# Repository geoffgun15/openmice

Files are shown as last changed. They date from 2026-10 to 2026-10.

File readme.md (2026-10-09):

# OpenMice

Custom PAW3395 rechargeable mouse, USB wireless receiver, and browser configurator.

Standalone repository: https://github.com/geoffgun15/openmice.
Migrated from the original fork with all eight commits retained and the
confidential PixArt PDF removed from every commit. Historical commit IDs changed.

**A1 is a routed prototype package.** Both boards pass KiCad electrical,
clearance, connectivity and schematic parity checks. Custom runtime and
bootloader builds, factory HEX, runtime UF2 and fabrication exports are included.
**Physical tests are NOT RUN: there is no assembled board.** Review the
[first-article procedure](docs/FIRST_ARTICLE.md) and
[fabrication requirements](docs/FABRICATION.md) before a prototype order.

| Component | Included |
|---|---|
| Mouse | Bare PAW3395, nRF52840 module, 1S LiPo charger/power path, five buttons + scroll |
| Receiver | Custom nRF52840 board, USB-C, BLE-to-USB HID and configuration bridge |
| Firmware | Corrected sensor startup/ID/timing, 16-bit motion, DPI, bindings, persistence |
| Editor | Web Serial, DPI, mouse/keyboard bindings, Apply/Save, import/export and demo |

The radio modules are soldered components on custom PCBs; nice!nano is no longer
used. BLE is the prototype radio; proprietary 1000 Hz wireless is not implemented.

- [Hardware files and validation status](hardware/README.md)
- [Setup, protocol and verification](docs/SETUP.md)
- [Mouse schematic](hardware/mouse/mouse.kicad_sch) / [PCB](hardware/mouse/mouse.kicad_pcb)
- [Receiver schematic](hardware/receiver/receiver.kicad_sch) / [PCB](hardware/receiver/receiver.kicad_pcb)
- [Browser editor](web/index.html)

## Board renders

KiCad assembly renders with all 51 mouse and 18 receiver components fitted.
The sensor, radio module, USB-C, charger and crystal use simplified visual models;
these images do not validate mechanical fit. The battery, main click switches
and scroll encoder connect externally. See [model details](hardware/libraries/3dmodels/README.md).

| Mouse PCB · 64 × 94 mm | Wireless receiver PCB · 28 × 54 mm |
|---|---|
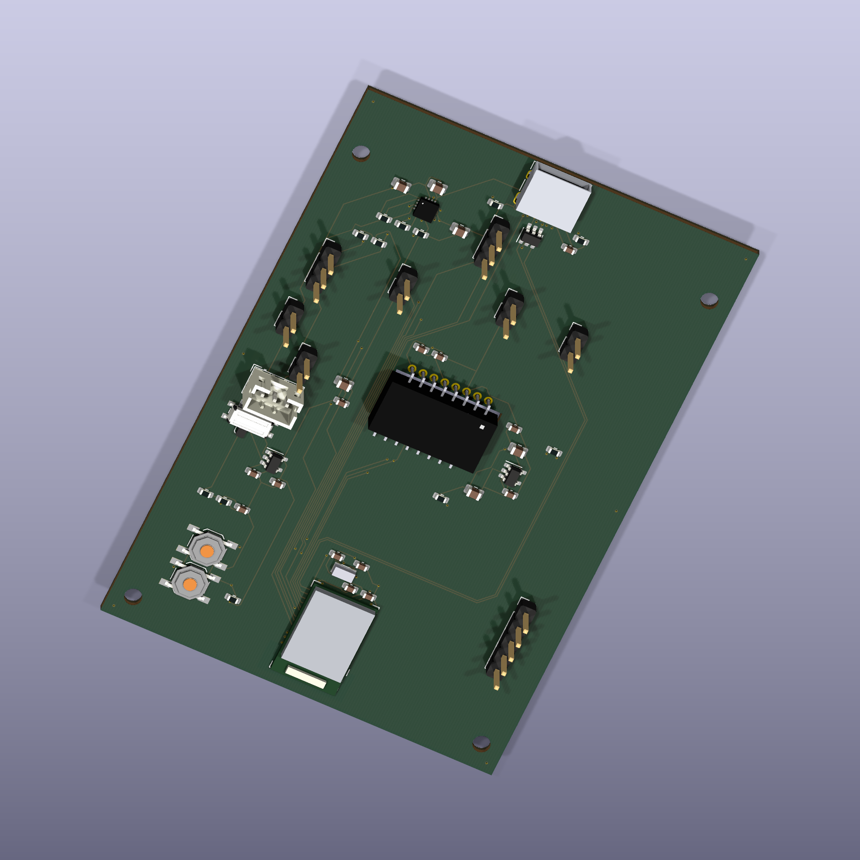
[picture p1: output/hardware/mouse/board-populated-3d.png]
Populated OpenMice mouse PCB with sensor, radio module and connectors
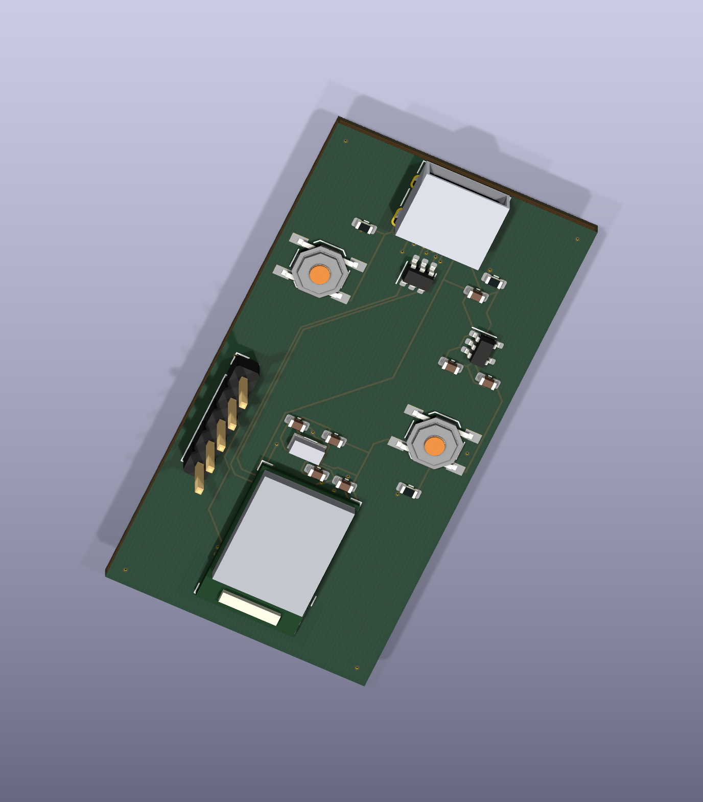
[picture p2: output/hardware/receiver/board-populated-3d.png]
Populated OpenMice wireless receiver PCB with radio module and USB-C
|  |  |

Bare PCB views: [mouse](output/hardware/mouse/board-3d.png) ·
[receiver](output/hardware/receiver/board-3d.png).

## Preview

```sh
python -m http.server 8765 --bind 127.0.0.1 --directory web
```

Open http://127.0.0.1:8765/ in desktop Chrome/Edge. Demo mode works without hardware.
A real connection requires the supplied runtime and mouse/receiver.

Native build details, hashes and CAD export workflow: [BUILD.md](docs/BUILD.md).

## Development

```sh
python -m unittest discover -s tests -v
node --test web/test.mjs
python tools/package_firmware.py
```

`tools/build_hardware.py` regenerates starting placements and overwrites manual edits.
The confidential sensor PDF is excluded from this public repository and its Git history.
Prototype assumptions: LM19-LSI optics,
64 x 94 mm mouse outline, external switch/encoder contacts, and a protected
300 mAh cell with compatible NTC temperature sensing.

Project code: MIT. Vendored KiCad libraries retain their upstream licenses;
see hardware/README.md. Obtain sensor documentation through an authorized source.

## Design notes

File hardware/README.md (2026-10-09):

# Hardware A1: routed prototype candidates

Both custom boards are routed and have zero findings in KiCad 10.0.6 ERC,
DRC, connectivity and schematic parity checks. Manufacturing exports are in
`output/hardware/` and fabrication ZIPs in `output/`. **Physical tests are NOT RUN.**

| Board | Outline | Components | Functional nets |
|---|---|---:|---:|
| Mouse | 64 × 94 mm | 51 | 39 |
| USB-C receiver | 28 × 54 mm | 18 | 13 |

Both boards use soldered Raytac MDBT50Q-1MV2 nRF52840 modules. The mouse has a
bare PAW3395DM-T6QU, 1.9 V sensor/LED rail, 3.0 V MCU/VDDIO rail, external contact
headers for five switches and a scroll encoder, USB-C, SWD and Pair/reset buttons.
The receiver connects by USB-C cable and bridges BLE input/configuration to USB.
Proprietary 1000 Hz wireless is not implemented.

BQ24072 provides charging and system power path for a protected 1S 3.7 V nominal
300 mAh LiPo pack with thermally attached compatible 10k NTC (J3 BAT+, GND, NTC).
USB100 mode caps total input at 100 mA; R_ISET 5.90k programs about 151 mA before
input/system limits, R_ILIM 3.09k is overridden, R_TMR 68k is about 9.1 hours nominal.
The switch is downstream of charging. Firmware battery telemetry is approximate;
pack protection handles over-discharge. USB suspend management is not implemented.

Sensor VDDREG is decoupled only. TLV70019 supplies sensor VDD/LED (5.6 ohm 1%
resistor); TLV70030 supplies VDDIO and MCU VDD/VDDH. DCCH is unconnected. Separate
5.1k CC resistors and USBLC6-2SC6 protect USB; no PD. External 32.768 kHz crystal
loading needs bench verification. The module includes its normal-mode DC/DC parts.

Four layers use outer signal routing and two solid inner GND reference planes,
all-layer antenna keep-outs, routed optical/mounting apertures and charger thermal
vias. USB routing is manually protected. Review the
[fabrication specification](../docs/FABRICATION.md) for stack-up, impedance, filled thermal vias, lens and BOM
requirements before a first-article order. No shell or optical fit validation exists.

Editable native schematics/boards, local libraries, routing DSN/SES, BOM, placement
CSV and CAD-check reports are included. Regeneration overwrites routing; see
[build workflow](../docs/BUILD.md). The unused MouseSwitch_D2F_DRAFT footprint is
not in either BOM and is not validated. Bench bring-up is in
[FIRST_ARTICLE.md](../docs/FIRST_ARTICLE.md).

## References and licenses

- PAW3395DM-T6QU datasheet v1.3 (8 Apr 2024): confidential reference, excluded
  from this public repository; obtain through an authorized source.
- [Raytac module datasheet](https://www.raytac.com/tw/download/index.php?index_id=24).
- [BQ2407x datasheet, including BQ24072](https://www.ti.com/lit/ds/symlink/bq24074.pdf).
- [TLV700 regulators](https://www.ti.com/product/TLV700).
- [KiCad footprints](https://github.com/KiCad/kicad-footprints) and
  [symbols](https://github.com/KiCad/kicad-symbols).

Vendored KiCad data retains upstream CC-BY-SA 4.0 licensing with the KiCad library
exception; see the [library license](https://www.kicad.org/libraries/license/).
Project code uses MIT. The confidential PixArt reference is not distributed.

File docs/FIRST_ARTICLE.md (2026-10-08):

# First article: not yet run

There is no assembled board. Every physical test below is **NOT RUN**. Record
board revision, firmware hashes, equipment, conditions and measured results;
do not infer a pass from the CAD checks or host tests.

1. Inspect solder joints, PAW seating, antenna keep-out and optical alignment.
   Check resistance from USB/battery/system/3.0 V/1.9 V rails to GND before power.
   Leave the battery disconnected initially. Use a current-limited USB supply.
2. Measure MCU/VDDIO at 3.0 V and sensor/LED at 1.9 V under startup and load.
   Check VDDREG against the PAW datasheet. Stop on excess current or heating.
   Confirm USB input stays within the selected 100 mA limit.
3. Connect an SWD probe to SWDIO, SWCLK, GND and target-reference 3.0 V.
   Never drive the target with a 5 V probe supply. Program and verify
   output/native/openmice-factory.hex, including UICR and bootloader settings.
   Confirm normal startup, Pair held during reset enters UF2, and SWD recovery.
4. Copy the mouse/receiver application payload to the corresponding CIRCUITPY
   drive and power-cycle. Confirm USB HID mouse, keyboard and configuration
   CDC enumerate; recovery storage remains accessible. Test runtime UF2 update.
5. Capture SPI with a logic analyser: mode 3, <=4 MHz, reset and startup waits,
   1 ms ±1% ready polling cadence, burst address delay, and CS timing. Confirm
   product ID 0x51/inverse 0xAE. Exercise unsuccessful initialization recovery.
   The compiled DWT polling helper fails explicitly on missed cadence, but this
   does not replace a waveform measurement.
6. Run `python tools/bench_config.py --port COMx --report results/wired.json`
   after installing pyserial. It tests hello/get, an invalid DPI rejection and
   live set/readback, then restores the original live configuration. It does
   not save or move the pointer. Repeat through the paired receiver.
7. Exercise DPI 50, 800, 1600, 9000 and 26000. Measure counts over a calibrated
   travel distance in both axes, jitter and lift-off on several surfaces.
   Test all five contacts, wheel direction, debounce and every binding class,
   including overlapping keyboard chords and release after disconnect.
8. Apply and Save a distinct configuration in the browser. Power-cycle and Read
   device. Cut power during repeated saves; recover the old or completed new
   profile, never corrupted data. Recheck receiver pairing after configuration
   saves and across power cycles (separate NVM erase pages).
9. Pair both devices after startup. Test automatic reconnect, receiver offline
   errors, fragmented traffic, interference/range and stale-input release within
   the 500 ms watchdog allowance. Record motion/input latency, packet loss and
   current; no wireless polling-rate or battery-life claim exists yet.
10. Connect the specified protected battery with NTC after polarity/ratings
    checks. Measure USB100 charging, charge termination, system power-path
    transitions, NTC hot/cold inhibition and case/charger temperature. Test with
    the battery supplier's limits. Measure active, idle and switched-off current
    and run battery endurance. MCU deep sleep/firmware cutoff are not implemented.

Acceptance: all physical measurements meet the applicable component datasheets
and chosen pack specifications; USB, input and persistence behave as above.
Document failures and revise the board/firmware before another article or larger
order. EMC/ESD and regulatory tests are separate from this prototype bring-up.

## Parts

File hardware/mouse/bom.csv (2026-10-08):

Reference | Value / part | Footprint | X mm | Y mm | Block
U1 | MDBT50Q-1MV2 | Raytac_MDBT50Q | 32 | 84 | controller
J1 | USB-C HRO TYPE-C-31-M-12 | USB_C | 32 | 3.6 | USB
U2 | USBLC6-2SC6 | SOT-23-6 | 38 | 7.6 | USB
R1 | 5.1k 1% | R_0603_1608Metric | 26 | 7.6 | USB
R2 | 5.1k 1% | R_0603_1608Metric | 29 | 7.6 | USB
U3 | TLV70030DDCR | SOT-23-5 | 13 | 61 | power
C1 | 1uF 10V X7R | C_0603_1608Metric | 11 | 64 | power
C2 | 4.7uF 6.3V X5R | C_0603_1608Metric | 15 | 64 | power
C3 | 100nF 10V X7R | C_0603_1608Metric | 32 | 75 | controller
C4 | 100nF 10V X7R | C_0603_1608Metric | 35 | 75 | controller
C5 | 1uF 10V X7R | C_0603_1608Metric | 35 | 10.6 | USB
Y1 | 32.768kHz 12.5pF ABS07 | Crystal_SMD_3215-2Pin_3.2x1.5mm | 30 | 73 | controller
C6 | 18pF C0G (tune) | C_0603_1608Metric | 28 | 71 | controller
C7 | 18pF C0G (tune) | C_0603_1608Metric | 32 | 71 | controller
J2 | SWD: VDD / SWDIO / SWDCLK / GND / RESET | PinHeader_1x05_P2.54mm_Vertical | 57 | 67 | debug
SW1 | PAIR TL3342 | SW_SPST_TL3342 | 10 | 78 | controls
SW2 | RESET TL3342 | SW_SPST_TL3342 | 10 | 84 | controls
R3 | 10k | R_0603_1608Metric | 14 | 84 | controller
U4 | PAW3395DM-T6QU | PAW3395DM_T6QU | 32 | 44 | sensor
U5 | TLV70019DDCR | SOT-23-5 | 46 | 48 | sensor
C8 | 1uF 10V X7R | C_0603_1608Metric | 47 | 51 | sensor
C9 | 10uF 6.3V X5R | C_0805_2012Metric | 45 | 44 | sensor
C10 | 100nF X7R | C_0603_1608Metric | 43 | 41 | sensor
C11 | 4.7uF X5R | C_0603_1608Metric | 25 | 35 | sensor
C12 | 100nF X7R | C_0603_1608Metric | 28 | 35 | sensor
C13 | 10uF X5R | C_0805_2012Metric | 17 | 45 | sensor
C14 | 100nF X7R | C_0603_1608Metric | 18 | 48 | sensor
C15 | 33uF 6.3V X5R | C_0805_2012Metric | 42 | 53 | sensor
R4 | 5.6R 1% | R_0603_1608Metric | 40 | 52 | sensor
R5 | 10k | R_0603_1608Metric | 50 | 42 | sensor
U6 | BQ24072RGTR | VQFN-16-1EP_3x3mm_P0.5mm_EP1.45x1.45mm | 16 | 14 | battery
J3 | Protected 1S 300mAh + 10k NTC (BAT/GND/NTC) | JST_PH_B3B-PH-K_1x03_P2.00mm_Vertical | 6 | 53 | battery
R6 | 5.90k 1% | R_0603_1608Metric | 11 | 18 | battery
R7 | 3.09k 1% | R_0603_1608Metric | 14 | 18 | battery
R8 | 68k 1% | R_0603_1608Metric | 17 | 18 | battery
C16 | 1uF 10V X7R | C_0805_2012Metric | 16 | 10 | battery
C17 | 10uF 6.3V X5R | C_0805_2012Metric | 20 | 17 | battery
C18 | 10uF 6.3V X5R | C_0805_2012Metric | 11 | 12 | battery
SW3 | Power PCM12 | SW_SPDT_PCM12 | 7 | 63 | battery
R9 | 100k 1% | R_0603_1608Metric | 6 | 70 | battery
R10 | 100k 1% | R_0603_1608Metric | 9 | 70 | battery
C19 | 100nF X7R | C_0603_1608Metric | 12 | 70 | battery
R11 | 100k | R_0603_1608Metric | 9 | 22 | battery
R12 | 100k | R_0603_1608Metric | 12 | 22 | battery
J4 | Charger status: GND / PGOOD / CHG | PinHeader_1x03_P2.54mm_Vertical | 6 | 26 | battery
J5 | BUTTON_LEFT contact | PinHeader_1x02_P2.54mm_Vertical | 18 | 25 | controls
J6 | BUTTON_RIGHT contact | PinHeader_1x02_P2.54mm_Vertical | 44 | 25 | controls
J7 | BUTTON_MIDDLE contact | PinHeader_1x02_P2.54mm_Vertical | 30 | 20 | controls
J8 | BUTTON_BACK contact | PinHeader_1x02_P2.54mm_Vertical | 5 | 39 | controls
J9 | BUTTON_FORWARD contact | PinHeader_1x02_P2.54mm_Vertical | 5 | 44 | controls
J10 | Encoder: A / GND / B | PinHeader_1x03_P2.54mm_Vertical | 27 | 12 | controls

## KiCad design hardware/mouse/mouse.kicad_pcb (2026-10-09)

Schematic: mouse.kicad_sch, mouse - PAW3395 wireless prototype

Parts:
C1, C5, C8: 1uF 10V X7R; C_0603_1608Metric
C2: 4.7uF 6.3V X5R; C_0603_1608Metric
C3, C4: 100nF 10V X7R; C_0603_1608Metric
C6, C7: 18pF C0G (tune); C_0603_1608Metric
C9, C17, C18: 10uF 6.3V X5R; C_0805_2012Metric
C10, C12, C14, C19: 100nF X7R; C_0603_1608Metric
C11: 4.7uF X5R; C_0603_1608Metric
C13: 10uF X5R; C_0805_2012Metric
C15: 33uF 6.3V X5R; C_0805_2012Metric
C16: 1uF 10V X7R; C_0805_2012Metric
J1: USB-C HRO TYPE-C-31-M-12; USB_C
J2: SWD: VDD / SWDIO / SWDCLK / GND / RESET; PinHeader_1x05_P2.54mm_Vertical
J3: Protected 1S 300mAh + 10k NTC (BAT/GND/NTC); JST_PH_B3B-PH-K_1x03_P2.00mm_Vertical
J4: Charger status: GND / PGOOD / CHG; PinHeader_1x03_P2.54mm_Vertical
J5: BUTTON_LEFT contact; PinHeader_1x02_P2.54mm_Vertical
J6: BUTTON_RIGHT contact; PinHeader_1x02_P2.54mm_Vertical
J7: BUTTON_MIDDLE contact; PinHeader_1x02_P2.54mm_Vertical
J8: BUTTON_BACK contact; PinHeader_1x02_P2.54mm_Vertical
J9: BUTTON_FORWARD contact; PinHeader_1x02_P2.54mm_Vertical
J10: Encoder: A / GND / B; PinHeader_1x03_P2.54mm_Vertical
R1, R2: 5.1k 1%; R_0603_1608Metric
R3, R5: 10k; R_0603_1608Metric
R4: 5.6R 1%; R_0603_1608Metric
R6: 5.90k 1%; R_0603_1608Metric
R7: 3.09k 1%; R_0603_1608Metric
R8: 68k 1%; R_0603_1608Metric
R9, R10: 100k 1%; R_0603_1608Metric
R11, R12: 100k; R_0603_1608Metric
SW1: PAIR TL3342; SW_SPST_TL3342
SW2: RESET TL3342; SW_SPST_TL3342
SW3: Power PCM12; SW_SPDT_PCM12
U1: MDBT50Q-1MV2; Raytac_MDBT50Q
U2: USBLC6-2SC6; SOT-23-6
U3: TLV70030DDCR; SOT-23-5
U4: PAW3395DM-T6QU; PAW3395DM_T6QU
U5: TLV70019DDCR; SOT-23-5
U6: BQ24072RGTR; BQ24072_RGT0016C
Y1: 32.768kHz 12.5pF ABS07; Crystal_SMD_3215-2Pin_3.2x1.5mm

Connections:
/BATTERY: C18.1, J3.1, R9.1, U6.2 (BAT), U6.3 (BAT)
/BATTERY_ADC: C19.1, R9.2, R10.1, U1.20 (P0.04/AIN2)
/BATTERY_NTC: J3.3, U6.1 (TS)
/BUTTON_BACK: J8.1, U1.46 (P0.22)
/BUTTON_FORWARD: J9.1, U1.48 (P0.24)
/BUTTON_LEFT: J5.1, U1.44 (P0.20)
/BUTTON_MIDDLE: J7.1, U1.45 (P0.23)
/BUTTON_RIGHT: J6.1, U1.43 (P0.21)
/CC1: J1.A5, R1.1
/CC2: J1.B5, R2.1
/CHARGER_ILIM: R7.1, U6.12 (ILIM)
/CHARGER_ISET: R6.1, U6.16 (ISET)
/CHARGER_TMR: R8.1, U6.14 (TMR)
/CHARGING: J4.3, R12.2, U6.9 (CHG)
/ENCODER_A: J10.1, U1.49 (P0.25)
/ENCODER_B: J10.3, U1.19 (P0.26)
/GND: C1.2, C2.2, C3.2, C4.2, C5.2, C6.2, C7.2, C8.2, C9.2, C10.2, C11.2, C12.2, C13.2, C14.2, C15.2, C16.2, C17.2, C18.2, C19.2, J1.A1, J1.A12, J1.B1, J1.B12, J1.S1, J2.4, J3.2, J4.1, J5.2, J6.2, J7.2, J8.2, J9.2, J10.2, R1.2, R2.2, R6.2, R7.2, R8.2, R10.2, SW1.2, SW2.2, U1.1 (GND), U1.2 (GND), U1.15 (GND), U1.33 (GND), U1.55 (GND), U2.2, U3.2, U4.3 (GND), U4.8 (GNDIO), U5.2, U6.4 (CE), U6.5 (EN2), U6.6 (EN1), U6.8 (VSS), U6.15 (TD), U6.17 (EP)
/LF_XL1: C6.1, U1.17 (XL1/P0.00), Y1.1
/LF_XL2: C7.1, U1.18 (XL2/P0.01), Y1.2
/MCU_RESET: J2.5, R3.2, SW2.1, U1.40 (~RESET~/P0.18)
/PAIR: SW1.1, U1.16 (P0.27)
/POWER_GOOD: J4.2, R11.2, U6.7 (PGOOD)
/SENSOR_IRQ: U1.27 (TRACEDATA2/P0.11), U4.9 (MOTION)
/SENSOR_LED_P: R4.2, U4.15 (LED_P)
/SENSOR_NCS: U1.38 (P0.16), U4.13 (NCS)
/SENSOR_RESET: U1.41 (P0.17), U4.14 (NRESET)
/SENSOR_VDDREG: C11.1, C12.1, U4.5 (VDDREG)
/SPI_MISO: R5.2, U1.39 (P0.15), U4.12 (MISO)
/SPI_MOSI: U1.37 (P0.13), U4.11 (MOSI)
/SPI_SCLK: U1.36 (P0.14), U4.10 (SCLK)
/SWDCLK: J2.3, U1.53 (SWDCLK)
/SWDIO: J2.2, U1.51 (SWDIO)
/SYSTEM: C17.1, SW3.1, U6.10 (OUT), U6.11 (OUT)
/SYSTEM_ON: C1.1, SW3.2, U3.1, U3.3
/USB_DM: J1.A7, J1.B7, U1.34 (D-), U2.3, U2.4
/USB_DP: J1.A6, J1.B6, U1.35 (D+), U2.1, U2.6
/USB_VBUS: C5.1, C16.1, J1.A4, J1.A9, J1.B4, J1.B9, U1.32 (VBUS), U2.5, U6.13 (IN)
/VDD_1V9: C9.1, C10.1, C15.1, R4.1, U4.4 (VDD), U5.5
/VDD_3V0: C2.1, C3.1, C4.1, C8.1, C13.1, C14.1, J2.1, R3.1, R5.1, R11.1, R12.1, U1.28 (VDD), U1.30 (VDDH), U3.5, U4.7 (VDDIO), U5.1, U5.3

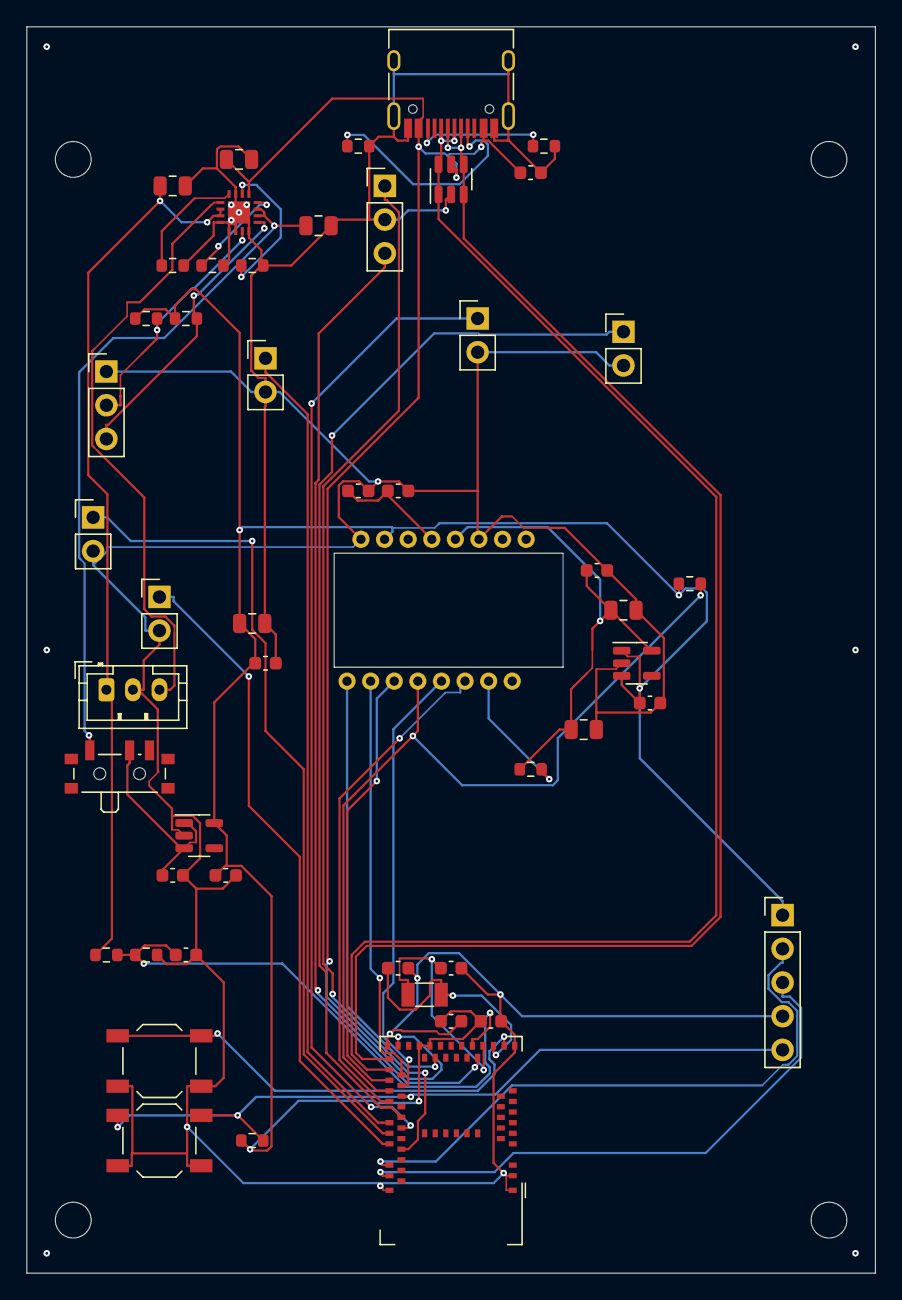
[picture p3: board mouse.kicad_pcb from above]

Board: 4 copper layers, 64.0 x 94.0 mm, 51 parts (0 on the bottom side), 39 nets.

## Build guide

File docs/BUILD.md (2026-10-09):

# Rebuild and verification

The supplied native files were compiled with ARM GNU 13.2.Rel1 on Windows using
MSYS2 make 4.4.1, Python 3.12, GCC 15.3 for mpy-cross, and the source commits in
output/native/manifest.json. Flash use is recorded in runtime-size.json. Both
devices share the runtime/bootloader; their code.py payloads differ.

CircuitPython 9.2.8 commit 361dbc02066f8d2b83c3a7f1f4993a9a590d1239 and Adafruit
nRF52 Bootloader 0.11.0 commit c67f0bcf0fa8e841426335b1bbde91cda6ca1f50 are used.
S140 **6.1.1 must match in both**. The board enables internal storage, a 12 KiB
NVM allocation, the external 32.768 kHz crystal, and no LED. BLE/Register/BusDevice
libraries are frozen from CircuitPython's pinned submodule commits.

Prerequisites: git, GNU make, native GCC, Python, ARM GNU 13.2.Rel1 on PATH;
CircuitPython's requirements-dev.txt Python build dependencies, intelhex and
adafruit-nrfutil 0.5.3.post16. Pin setuptools below 81 for that older DFU utility
(the supplied build used 80.9.0). MSYS2 also needs diffutils and unzip. On MSYS2,
clear the Windows `OS` environment variable before make and use POSIX paths.

Run `bash tools/build_native.sh /absolute/path/to/new-build-directory` from a
configured shell. This creates fresh checkouts; it does not erase existing ones.
Full recursive submodules can be large. The script reflects the successful build
steps; the supplied binaries were built incrementally, not in a second clean-room
run. Exact source/submodule provenance and output SHA-256 hashes are included.

The narrowly scoped PacketBuffer header patch exposes an internal declaration
needed by _bleio when optional BLE serial/file workflows are disabled. The native
openmice_native.poll_ready helper uses the Cortex-M4 cycle counter for the PAW
startup polling cadence and detects missed deadlines; radio interrupts remain
enabled. Other sensor transactions remain Python driver code. Physical SPI
waveforms and USB enumeration must still be measured.

Host checks: `python -m unittest discover -s tests -v` and
`node --test web/test.mjs`. Regenerate the application ZIPs with
`python tools/package_firmware.py`.

CAD tooling: KiCad 10.0.6, Freerouting 2.5.0, Java 25.0.4.1.
The generator overwrites the native designs with unrouted starting placements:

1. Run tools/build_hardware.py with Python.
2. Run tools/prepare_routing.py using KiCad's Python/pcbnew.
3. Export native schematic netlists with `kicad-cli sch export netlist` into each
   board's .net file. Hand USB routes are locked and included in the DSN.
4. Run Freerouting headless with the board's routing/*.dsn to produce *.ses, or
   reuse the checked-in session if geometry and electrical model are unchanged.
   Route only outer layers; use 0.17 mm defaults with 0.125 mm minimum neckdowns.
5. Run tools/finalize_board.py using KiCad Python: import sessions, clean redundant
   vias, complete receiver power/ground, add charger thermal vias, two GND planes,
   perimeter ties, all-layer RF keep-out, and schematic NC-net assignments.
6. Using KiCad's Python/pcbnew, run
   `python tools/export_hardware.py --kicad-cli /path/to/kicad-cli`.
   It refuses fabrication exports if ERC, DRC, connectivity or parity fails.

Run `python tools/verify_release.py` to verify native image records/checksums,
UF2 family/content, nonoverlapping factory regions, native manifest, CAD results
and matching application/fabrication archives. It refreshes hardware output hashes
after optional PNG previews are rendered.

Final native reports have zero findings on both boards. Configured rule checks
are CAD checks; stack-up impedance, mechanical fit and bench operation are not
proved by these reports. Check manufacturing assumptions in FABRICATION.md.

Project code is MIT. Native bundles include CircuitPython, Adafruit bootloader,
Nordic SoftDevice and frozen-library license files. Vendored KiCad footprints
retain their upstream licensing. The confidential PixArt PDF is excluded
from this public repository and its complete Git history.

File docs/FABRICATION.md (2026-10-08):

# A1 prototype fabrication specification

The supplied files are routed prototype candidates. Physical validation is NOT
RUN. Before ordering a first article, confirm the stack-up, lens fit and assembly
process below with the fabricator. This package is not a production release.

| Item | Specification |
|---|---|
| Mouse outline | 64 × 94 mm, four 2.7 mm routed mounting apertures |
| Receiver outline | 28 × 54 mm, USB-C cable connection |
| Layers | F.Cu signals / In1.Cu GND / In2.Cu GND / B.Cu signals |
| Finished thickness | Nominal 1.6 mm, confirm optics before manufacture |
| Outer copper | 35 µm nominal |
| Outer dielectric | Nominal 0.10 mm, FR4 Er approximately 4.2 |
| Inner core | Approximately 1.26 mm; vendor completes stack-up |
| USB impedance | Target 90 Ω differential; vendor must solve stack-up |
| USB geometry | 0.17 mm width / 0.15 mm gap; impedance not measured |
| Minimum track/clearance | 0.125 / 0.125 mm |
| Through vias | 0.50 mm copper / 0.20 mm finished drill |
| Copper to cut edge | 0.25 mm minimum |
| Finish | ENIG recommended for prototype assembly |

Gerbers include four copper layers, masks, silk, paste and Edge.Cuts. Excellon
files separate plated and nonplated holes. Edge.Cuts contains mouse optical and
mounting apertures: route these, do not treat them as artwork. No blind vias.
Review the exported drill-map SVG and copper layers against the native board.

The BQ24072 exposed pad is 1.68 mm square, with a 1.55 mm paste aperture
(approximately 85% coverage) and four 0.20 mm thermal vias. **Fill/plug and cap
these vias before assembly** to prevent solder loss. One corner via is replaced
by a central via to avoid the rear configuration trace. All other vias are
tented. Confirm paste thickness and reflow profile with the assembler.

The PAW3395 is through-hole and needs its matching optical assembly. The
17.26 × 8.60 mm aperture is based on the supplied sensor drawing. LM19-LSI lens,
1.6 mm board fit, sensor seating height and lens-to-surface distance require an
actual mechanical fit check. No shell is supplied. Switches and encoder attach
to headers; the bare board is not a complete enclosed mouse.

Keep copper/components/cables/metal away from the radio antenna areas on all
layers. Housing and battery placement can change antenna performance. Raytac
module approval does not establish approval of this complete product.

BOM values and placement CSV are engineering inputs, not a turnkey assembly
order. Confirm supplier part numbers/package variants, regulator pinouts, USB-C
connector HRO TYPE-C-31-M-12, PAW3395DM-T6QU and Raytac MDBT50Q-1MV2. Use 1%
charger/LED/divider resistors, X5R/X7R capacitors with voltage and DC-bias margin,
USB capacitors rated at least 10 V, and battery/system capacitors at least 6.3 V.
Do not silently substitute charger, optics or antenna modules.

Use a protected single-cell 3.7 V LiPo pack, nominal 300 mAh, with compatible
thermally attached 10 kΩ NTC. J3 is BAT+, GND, NTC. Confirm polarity before
connection. Charger USB100 selection caps total input at 100 mA; actual charge
current is lower while the system runs. See FIRST_ARTICLE.md for bring-up.

Checks: KiCad 10.0.6 ERC, DRC and schematic parity are stored under
output/hardware/{mouse,receiver}. Zero findings establish CAD consistency under
the configured rules, not optical, RF, thermal, EMC or physical functionality.

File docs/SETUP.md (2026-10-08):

# Setup, protocol and verification

**A1 status:** routed boards pass KiCad ERC/DRC and schematic parity. Native
runtime and bootloader are compiled and packaged. Physical tests are NOT RUN.
Read [first-article procedure](FIRST_ARTICLE.md) before powering an assembled board.

## Runtime and application

Both devices use the custom openmice_nrf52840 runtime, not a nice!nano runtime.
P0.15 is sensor MISO and must not drive a status LED. The runtime includes frozen
BLE dependencies and the native PAW startup polling helper.

For a blank board, use an SWD probe to program and verify
`output/native/openmice-factory.hex`. It includes MBR, S140 6.1.1, bootloader,
application and UICR/valid-bank settings. Confirm probe voltage and target pinout.
No board has yet been flashed. Do not use a commercial-board bootloader.

For runtime updates after provisioning, hold Pair during reset to enter the
bootloader and copy `output/native/openmice-runtime.uf2` to its UF2 drive.
The bootloader update UF2 in the native bundle is a different image and is
only for bootloader maintenance. SWD is the recovery path.

Copy contents of `output/openmice-mouse.zip` or `output/openmice-receiver.zip`
to the corresponding CIRCUITPY drive. No external BLE bundle is needed.
Power-cycle after changing boot.py. Mouse report ID 2 and keyboard ID 1 share
one HID interface; the configuration CDC channel and recovery storage remain
enabled. Enumeration and recovery must be verified on the first physical board.

The USB ID 1209:0001 is a shared private-test ID; allocate a unique ID for wider
distribution. Source/build steps and hashes are in [BUILD.md](BUILD.md).

## Pairing and browser

Connect the receiver using a USB-C data cable, power the mouse, and hold Pair on
both devices until discovery/bonding completes. The receiver then stores the
mouse's address and reconnects to it. Hold both Pair buttons to replace the peer.
Address rotation/privacy support is not implemented; firmware changes that alter
the mouse's static address require pairing again.

The mouse gates application traffic on paired state. Initial bonding uses
Just Works with no authenticated identity confirmation; pair in a controlled
setting. This is a prototype trust model that needs physical verification.

USB on the mouse selects wired input. The receiver bridges configuration to the
wireless mouse. It releases held inputs after 500 ms without a report. Wireless
motion is scheduled at 16 ms intervals and input-state changes are sent sooner;
BLE/Python add variable latency. No 1000 Hz wireless performance is claimed.

Start the editor from the repository:

```sh
python -m http.server 8765 --bind 127.0.0.1 --directory web
```

Open [OpenMice Studio](http://127.0.0.1:8765/) in desktop Chrome/Edge, choose
Connect device and select the mouse/receiver configuration serial port. Web
Serial needs localhost or HTTPS. A handshake validates name and protocol.
An offline mouse produces an explicit receiver error.

Apply changes updates live settings; Save to mouse applies the displayed profile
and persists it. Read device replaces displayed edits with device settings.
Demo mode changes only browser state and disables device Save/Read.

## Protocol v1

Newline-delimited UTF-8 JSON, incoming device frames bounded at 480 bytes.
Integer IDs are echoed in replies.

```json
{"id":1,"cmd":"hello"}
{"id":2,"cmd":"get"}
{"id":3,"cmd":"set","config":{"dpi":1600,"bindings":["left","right","middle","key:CTRL+C","forward"]}}
{"id":4,"cmd":"save"}
```

Replies have ok/config or ok:false/error. Hello includes device:OpenMice and
protocol:1; mouse replies include approximate battery_mv. The receiver consumes
wireless `motion:[dx,dy,wheel,button_mask,keycodes]` and forwards command replies.
DPI is 50–26000 in steps of 50. Bindings are mouse actions, none, or key: plus
1–6 distinct UI-supported key names joined by +.

Config uses two checksummed 4096-byte NVM slots on separate flash erase pages,
bytes 0–8191. Receiver peer identity starts at offset 8192 in a third page.
The native runtime reserves 12 KiB. Preserve this layout; smaller generic-runtime
allocations are incompatible.

## Verification

Completed: 18 host Python tests and five JavaScript tests. Coverage includes
sensor startup/fallback, signed motion, SPI cleanup, DPI/ripple control, validation,
page-erasure power interruption, duplicate bindings, debounce, quadrature, HID
lengths/distinct report IDs, partial CDC writes and hardware pin mapping.
The browser demo was exercised with DPI and a keyboard side-button binding.

Both boards pass native KiCad 10.0.6 ERC, DRC, connectivity and schematic parity.
ARM GNU 13.2.Rel1 compiled the custom CircuitPython 9.2.8 runtime and Adafruit
0.11.0 bootloader with matching S140 6.1.1. These are build/host checks only.

Physical tests are NOT RUN. USB enumeration, SPI timing, optics/CPI, input behavior,
persistence on hardware, pairing/reconnect, charging/NTC/thermal behavior, current,
range and latency remain in [FIRST_ARTICLE.md](FIRST_ARTICLE.md). The serial bench
harness is supplied but has not been run against a board. PAW rest mode is retained;
MCU deep sleep and firmware low-battery shutdown are not implemented. Pack
protection is required, and battery life is not measured.

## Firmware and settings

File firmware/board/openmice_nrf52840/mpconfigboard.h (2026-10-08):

// SPDX-License-Identifier: MIT
#pragma once
#include "nrfx/hal/nrf_gpio.h"
#define MICROPY_HW_BOARD_NAME "OpenMice nRF52840 prototype"
#define MICROPY_HW_MCU_NAME "nRF52840"
#define BOARD_HAS_CRYSTAL 1
#define CIRCUITPY_INTERNAL_NVM_SIZE (12 * 1024)
// Deliberately no status LED: P0.15 is the sensor MISO, not an LED.
#define DEFAULT_SPI_BUS_SCK (&pin_P0_14)
#define DEFAULT_SPI_BUS_MOSI (&pin_P0_13)
#define DEFAULT_SPI_BUS_MISO (&pin_P0_15)

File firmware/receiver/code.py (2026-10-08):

"""BLE central -> USB HID and bidirectional configuration bridge."""
import time
import json
import digitalio
import microcontroller
import usb_cdc
from adafruit_ble import BLERadio
from adafruit_ble.advertising.standard import ProvideServicesAdvertisement
from adafruit_ble.services.nordic import UARTService
from config import Lines,TxBuffer,frame
from hid_output import Output

hid = Output()
ble = BLERadio()
pair_button = digitalio.DigitalInOut(microcontroller.pin.P0_27)
pair_button.switch_to_input(pull=digitalio.Pull.UP)
cdc = usb_cdc.data
cdc.timeout = 0
cdc.write_timeout = 0
peer_offset = 8192 # dedicated third erase page, separate from config slots
raw_peer = bytes(microcontroller.nvm[peer_offset:peer_offset+10])
peer = raw_peer[4:] if raw_peer[:4] == b"OMP1" else None
connection = uart = None
usb_lines,radio_lines = Lines(),Lines()
last_motion = time.monotonic()
usb_connected = False
usb_tx = TxBuffer()

def reply(data):
    try:
        usb_tx.append(data)
    except RuntimeError:
        usb_tx.reset()

while True:
    if not connection or not connection.connected:
        hid.release()
        radio_lines.reset()
        if uart:
            uart.deinit()
            uart = None
        connection = None
        for adv in ble.start_scan(ProvideServicesAdvertisement,timeout=0.25):
            address = bytes(adv.address.address_bytes)
            known = peer is not None and address == peer
            pairing = not pair_button.value
            if UARTService not in adv.services or not (known or (pairing and adv.complete_name == "OpenMice")):
                continue
            ble.stop_scan()
            try:
                candidate = ble.connect(adv,timeout=2)
                # Hold mouse and receiver Pair buttons for first bond.
                candidate.pair(bond=True)
                if not candidate.paired:
                    candidate.disconnect()
                    break
                connection = candidate
                uart = connection[UARTService]
                connection.connection_interval = 7.5
                if pairing:
                    microcontroller.nvm[peer_offset:peer_offset+10] = b"OMP1"+address
                    peer = address
                last_motion = time.monotonic()
            except (OSError,RuntimeError):
                if connection and connection.connected:
                    connection.disconnect()
                connection = None
            break
    if cdc.connected != usb_connected:
        usb_lines.reset()
        usb_tx.reset()
        usb_connected = cdc.connected
    if cdc.connected and cdc.in_waiting:
        for raw in usb_lines.feed(cdc.read(min(128,cdc.in_waiting)) or b""):
            try:
                request = json.loads(raw.decode())
                request_id = request.get("id") if isinstance(request,dict) else None
                if connection and connection.connected and uart:
                    uart.write(raw+b"\n")
                else:
                    reply(frame({"id":request_id,"ok":False,"error":"Mouse offline. Pair or power on the mouse."}))
            except (ValueError,UnicodeError,OSError,RuntimeError):
                reply(frame({"id":None,"ok":False,"error":"Invalid request or wireless write failed"}))
    if connection and connection.connected and uart and uart.in_waiting:
        for raw in radio_lines.feed(uart.read(min(128,uart.in_waiting)) or b""):
            try:
                message = json.loads(raw.decode())
                if isinstance(message,dict) and "motion" in message:
                    motion = message["motion"]
                    if not isinstance(motion,list) or len(motion)!=5:
                        raise ValueError("Invalid wireless motion")
                    hid.report(*motion)
                    last_motion = time.monotonic()
                elif cdc.connected and isinstance(message,dict) and "ok" in message:
                    reply(raw+b"\n")
            except (ValueError,UnicodeError,OSError,RuntimeError):
                hid.release()
    # Full button/key snapshots + watchdog prevent stuck keys on radio loss.
    if time.monotonic()-last_motion > 0.5:
        hid.release()
        last_motion = time.monotonic()
    if cdc.connected:
        try:
            usb_tx.flush(cdc)
        except OSError:
            usb_tx.reset()
    time.sleep(0.001)

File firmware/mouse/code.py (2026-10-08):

"""Wired USB + BLE prototype. No guaranteed gaming polling rate."""
import time
import json
import busio
import digitalio
import microcontroller
import supervisor
import usb_cdc
import analogio
from adafruit_ble import BLERadio
from adafruit_ble.advertising.standard import ProvideServicesAdvertisement
from adafruit_ble.services.nordic import UARTService
from paw3395 import PAW3395
from config import Store, ConfigAPI, Lines, TxBuffer, frame
from inputs import Debounce, Quadrature, aggregate
from hid_output import Output

def output(pin, value):
    port = digitalio.DigitalInOut(pin)
    port.switch_to_output(value=value)
    return port
def input_pin(pin):
    port = digitalio.DigitalInOut(pin)
    port.switch_to_input(pull=digitalio.Pull.UP)
    return port

p = microcontroller.pin
spi = busio.SPI(p.P0_14,MOSI=p.P0_13,MISO=p.P0_15)
sensor = PAW3395(spi,output(p.P0_16,True),output(p.P0_17,True))
irq = input_pin(p.P0_11)
contacts = [input_pin(pin) for pin in (p.P0_20,p.P0_21,p.P0_23,p.P0_22,p.P0_24)]
encoder_a, encoder_b = input_pin(p.P0_25),input_pin(p.P0_26)
pair_button = input_pin(p.P0_27)
battery = analogio.AnalogIn(p.P0_04)
debouncers = [Debounce() for _ in contacts]
encoder = Quadrature((int(encoder_a.value)<<1)|int(encoder_b.value))
sensor.initialize()
api = ConfigAPI(sensor,Store(microcontroller.nvm))
hid = Output()
ble = BLERadio()
ble.name = "OpenMice"
uart = UARTService()
advertisement = ProvideServicesAdvertisement(uart)
advertisement.complete_name = "OpenMice"
usb_lines, ble_lines = Lines(),Lines()
cdc = usb_cdc.data
cdc.timeout = 0
cdc.write_timeout = 0
next_report, next_recovery = 0,0
dx = dy = wheel = 0
previous = None
last_state = 0
was_usb, was_ble, was_cdc = False,False,False
usb_tx = TxBuffer()
errors = 0

def command(raw):
    try:
        result = api.handle(json.loads(raw.decode()))
        result["battery_mv"] = int(battery.value/65535*battery.reference_voltage*2000)
        return result
    except (ValueError, UnicodeError):
        return {"id":None,"ok":False,"error":"Invalid JSON"}

while True:
    now = time.monotonic()
    wired = supervisor.runtime.usb_connected
    wireless = ble.connected and all(connection.paired for connection in ble.connections)
    if wired and not was_usb:
        try:
            hid.release()
        except (OSError,RuntimeError):
            pass
        previous = None
    if wired and not was_usb and wireless:
        try:
            uart.write(frame({"motion":[0,0,0,0,[]]}))
        except (OSError,RuntimeError):
            pass
    if not ble.connected and not ble.advertising:
        # Name-based discovery is for prototype use; receiver stores peer address.
        ble.start_advertising(advertisement,interval=0.1)
    if ble.connected and not wireless and not pair_button.value:
        for connection in ble.connections:
            if not connection.paired:
                connection.pair(bond=True)
    if (was_usb and not wired) or (was_ble and not wireless):
        dx = dy = wheel = 0
        previous = None
        if wired:
            hid.release()
    if cdc.connected != was_cdc:
        usb_lines.reset()
        usb_tx.reset()
        was_cdc = cdc.connected
    if wireless != was_ble:
        ble_lines.reset()
    was_usb,was_ble = wired,wireless
    if cdc.connected and cdc.in_waiting:
        for line in usb_lines.feed(cdc.read(min(cdc.in_waiting,128)) or b""):
            try:
                usb_tx.append(frame(command(line)))
            except RuntimeError:
                usb_tx.reset()
    if cdc.connected:
        try:
            usb_tx.flush(cdc)
        except OSError:
            usb_tx.reset()
    if wireless:
        try:
            if uart.in_waiting:
                for line in ble_lines.feed(uart.read(min(uart.in_waiting,128)) or b""):
                    uart.write(frame(command(line)))
        except (OSError,RuntimeError):
            ble_lines.reset()
            for connection in ble.connections:
                if connection.connected:
                    connection.disconnect()
    pressed = [debounce.update(not port.value,now) for debounce,port in zip(debouncers,contacts)]
    buttons,keys = aggregate(pressed,api.config["bindings"])
    wheel += encoder.update((int(encoder_a.value)<<1)|int(encoder_b.value))
    if now >= next_recovery and not irq.value:
        try:
            x,y = sensor.motion()
            dx += x
            dy += y
            errors = 0
        except (OSError,RuntimeError):
            errors += 1
            if errors >= 3:
                if wired:
                    hid.release()
                try:
                    sensor.initialize()
                    sensor.set_dpi(api.config["dpi"])
                    errors = 0
                except (OSError,RuntimeError):
                    next_recovery = now+1
    interval = 0.001 if wired else 0.016
    state = (buttons,keys)
    if now >= next_report or state != previous:
        if dx or dy or wheel or state != previous or now-last_state > 0.1:
            x,y,w = max(-32768,min(32767,dx)),max(-32768,min(32767,dy)),max(-127,min(127,wheel))
            try:
                if wired:
                    hid.report(x,y,w,buttons,keys)
                elif wireless:
                    uart.write(frame({"motion":[x,y,w,buttons,keys]}))
                else:
                    dx = dy = wheel = 0
                if wired or wireless:
                    dx -= x
                    dy -= y
                    wheel -= w
                previous,last_state = state,now
            except (OSError,RuntimeError):
                dx = dy = wheel = 0
                previous = None
        next_report = now+interval
    time.sleep(0.0005)

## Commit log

2026-10-08 Add wireless mouse prototype, PCB drafts and web configurator
    Implement PAW3395 driver corrections, configurable HID bindings, persistent profiles and a BLE receiver bridge. Add the browser editor, application packages and host tests. Include unrouted mouse/receiver design drafts and document pending CAD checks, native builds and physical validation.
    [bom.csv, mouse.kicad_pcb, mouse.kicad_sch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]
2026-10-08 Route A1 prototype boards and build native firmware; bench validation pending
    [bom.csv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]
2026-10-08 Preserve release checksums and application bytes across Windows checkouts
    [bom.csv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]
2026-10-09 Add 3D renders of mouse and receiver PCBs
2026-10-09 Show mouse and receiver PCB renders in README
2026-10-09 Add populated PCB renders and portable component models
    [mouse.kicad_pcb, receiver.kicad_pcb]
